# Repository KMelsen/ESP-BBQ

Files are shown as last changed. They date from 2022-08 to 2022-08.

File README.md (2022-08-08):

# ESP-BBQ
This contains all files for an ESP32 based WiFi BBQ thermometer.

* ```ESP-BBQ```: Contains the Arduino sketch with the code
* ```KiCad_PCB```: Contains all KiCad (6.0) files for the PCB
* ```Gerber_Drill_PCB.zip```: ZIP with all files needed to order the PCB
* ```PJ-210B_4-pin_2.5mm_jack.kicad_mod```: Custom KiCad footprint for the PJ-210B 4-pin 2.5mm jack

# Required parts
* **1x** PCB
* **1x** 38-pin ESP32
* **6x** PJ-210B 4-pin 2.5mm jack
* **6x** 100 Nf (104) capacitor
* **6x** 100K Ohm resistor
* **6x** 100K NTC thermistor probe
* **1x** 1.3 inch 128x64 I2C OLED display
* **2x** 19-pin 2.54mm female connector
* **1x** 4-pin 2.54mm female connector
* **8x** M3 20mm bolt
* **16x** M3 nut




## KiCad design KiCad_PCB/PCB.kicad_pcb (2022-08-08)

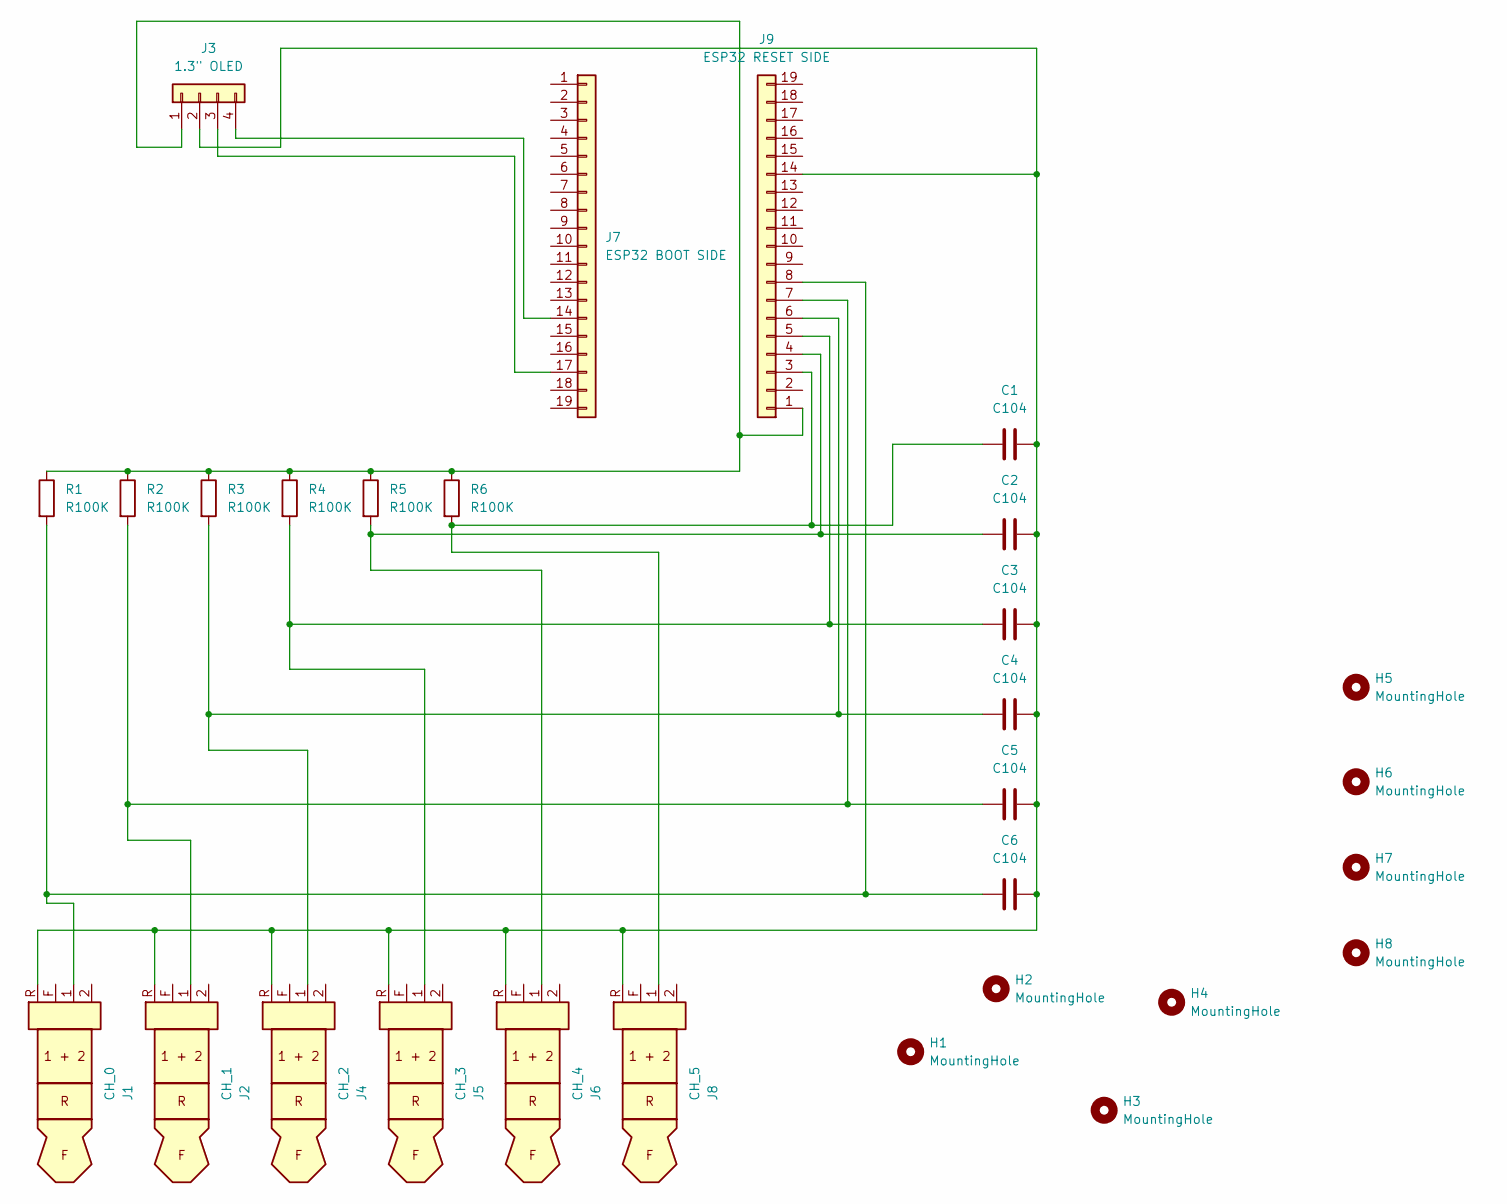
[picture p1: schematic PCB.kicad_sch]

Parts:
C1, C2, C3, C4, C5, C6: C104; C_Disc_D5.0mm_W2.5mm_P2.50mm
H1, H2, H3, H4, H5, H6, H7, H8: MountingHole; MountingHole_3.2mm_M3
J1: CH_0
J2: CH_1
J3: 1.3" OLED; PinSocket_1x04_P2.54mm_Vertical
J4: CH_2
J5: CH_3
J6: CH_4
J7: ESP32 BOOT SIDE; PinSocket_1x19_P2.54mm_Vertical
J8: CH_5
J9: ESP32 RESET SIDE; PinSocket_1x19_P2.54mm_Vertical
R1, R2, R3, R4, R5, R6: R100K; R_Axial_DIN0207_L6.3mm_D2.5mm_P7.62mm_Horizontal

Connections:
unnamed: C1.1, J8.1, J9.3, R6.2
unnamed: C1.2, C2.2, C3.2, C4.2, C5.2, C6.2, J1.R, J2.R, J3.2, J4.R, J5.R, J6.R, J8.R, J9.14
unnamed: C2.1, J6.1, J9.4, R5.2
unnamed: C3.1, J5.1, J9.5, R4.2
unnamed: C4.1, J4.1, J9.6, R3.2
unnamed: C5.1, J2.1, J9.7, R2.2
unnamed: C6.1, J1.1, J9.8, R1.2
unnamed: J3.1, J9.1, R1.1, R2.1, R3.1, R4.1, R5.1, R6.1
unnamed: J3.3, J7.17
unnamed: J3.4, J7.14

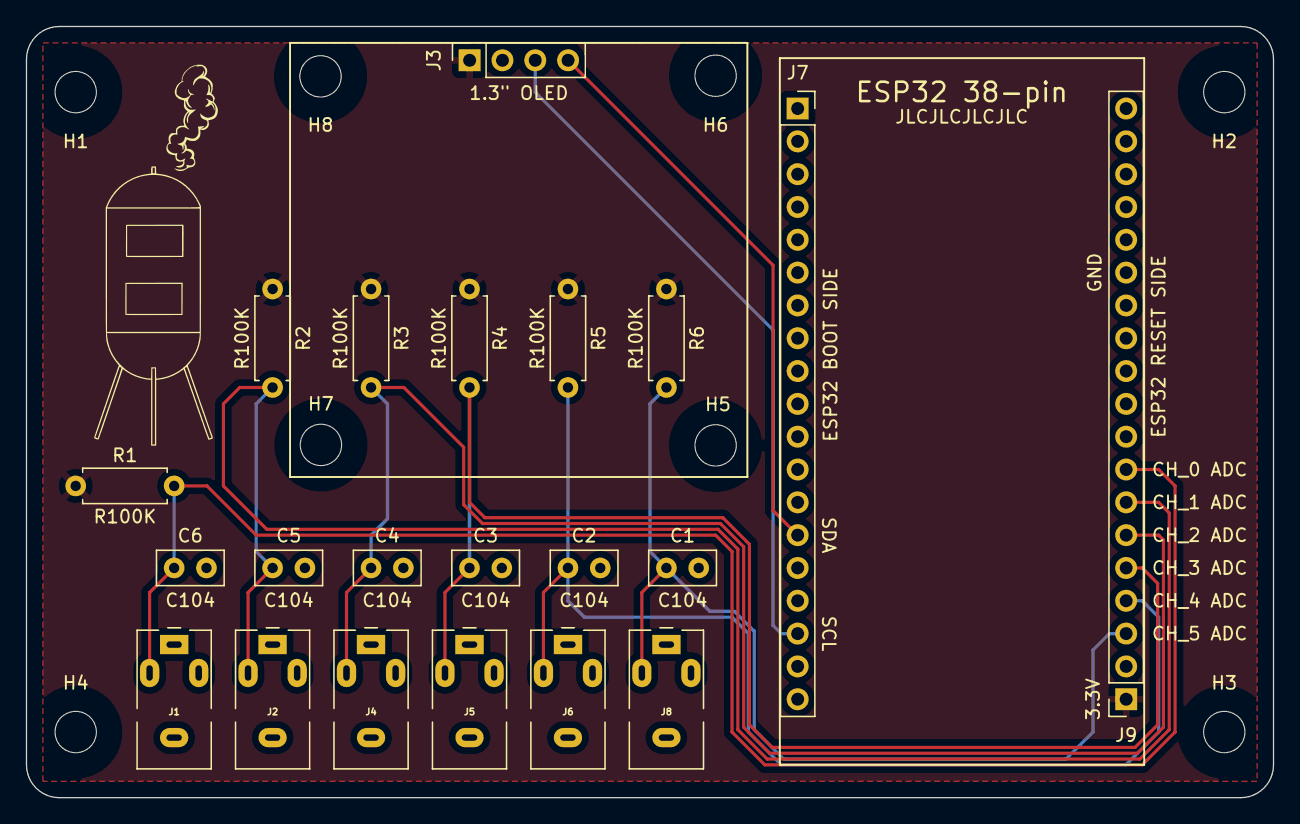
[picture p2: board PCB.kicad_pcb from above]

Board: 2 copper layers, 96.5 x 59.7 mm, 29 parts (0 on the bottom side), 10 nets.

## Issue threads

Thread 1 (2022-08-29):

Possible to calculate in Celsius website?

Relex28, 2022-08-29:
Hi and thank you for this amazing sharing!

is it possible to also convert the temperature to celcius in the website as done on the screen?

kind regards.

KMelsen, 2022-08-29:
```
String calTempF(int channel_pin) {
  float R = calculateResistance(channel_pin);
  float temp_K = 1.0 / (STEINHART_A + (STEINHART_B * log(R)) + (STEINHART_C * pow(log(R), 3.0)));
  float temp_C = round(temp_K - 273.15);
  int cal_temp_C = round(4.95152 + 0.7959 * temp_C);
  if (cal_temp_C < -100) {
    String cal_temp_F = "No probe connected";
    return String(cal_temp_F);
  } else {
    String cal_temp_F = String(round(cal_temp_C * 9 / 5 + 32));
    return String(cal_temp_F);
  }
}
```

You can change the line `String cal_temp_F = String(round(cal_temp_C * 9 / 5 + 32));` to return the temperature in Celsius instead of Fahrenheit.

Then just change the sign from `&deg;F` to `&deg;C` in for all channels
```
    <tr>
    <td><strong>Channel 0&nbsp;&nbsp;&nbsp;&nbsp;&nbsp;&nbsp;&nbsp;&nbsp;&nbsp;&nbsp;&nbsp;&nbsp;</strong>
    </td>
    <td id="ch0tempf" style="text-align:right;">%CH0TEMPF%</td>
    <td>&nbsp;&nbsp;&deg;F</td>
    </tr>
```

Relex28, 2022-08-29:
Many thanks, changed the lines and it works perfect.

Closed 2022-08-29.

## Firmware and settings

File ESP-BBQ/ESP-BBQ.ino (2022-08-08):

// Include libraries
#include <WiFi.h>
#include <ESPAsyncWebServer.h>
#include <SPI.h>
#include <Wire.h>
#include <Adafruit_GFX.h>
#include <Adafruit_SH110X.h>

// OLED information
#define I2C_ADDRESS 0x3C
#define SCREEN_WIDTH 128
#define SCREEN_HEIGHT 64
#define OLED_RESET -1
Adafruit_SH1106G display = Adafruit_SH1106G(SCREEN_WIDTH, SCREEN_HEIGHT, &Wire, OLED_RESET);

// Number of ADC samples for temperature calculation
const int samples = 50;

// Define input channels
#define CH0_INPUT 33
#define CH1_INPUT 32
#define CH2_INPUT 35
#define CH3_INPUT 34
#define CH4_INPUT 39
#define CH5_INPUT 36

// Define resistor and steinhart values
float RESISTOR = 99700;
float STEINHART_A = 0.5508197510e-3;
float STEINHART_B = 2.381337093e-4;
float STEINHART_C = 0.3546777196e-7;

// String temperature variables
String cal_temp_ch0_F = "";
String cal_temp_ch1_F = "";
String cal_temp_ch2_F = "";
String cal_temp_ch3_F = "";
String cal_temp_ch4_F = "";
String cal_temp_ch5_F = "";

// Splash screen logo bitmap, 128x64px
const unsigned char splash_bitmap [] PROGMEM = {
0x00, 0x00, 0x00, 0x00, 0x00, 0x00, 0x00, 0x00, 0x00, 0x00, 0x00, 0x00, 0x00, 0x00, 0x00, 0x00, 
0x00, 0x00, 0x00, 0x00, 0x00, 0x00, 0x00, 0x00, 0x00, 0x00, 0x00, 0x00, 0x00, 0x00, 0x00, 0x00, 
0x00, 0x00, 0x00, 0x00, 0x00, 0x00, 0x00, 0x00, 0x00, 0x00, 0x00, 0x00, 0x00, 0x20, 0x00, 0x00, 
0x00, 0x00, 0x00, 0x00, 0x00, 0x00, 0x00, 0x00, 0x00, 0x00, 0x00, 0x00, 0x00, 0x20, 0x00, 0x00, 
0x00, 0x00, 0x00, 0x00, 0x00, 0x00, 0x00, 0x00, 0x00, 0x00, 0x00, 0x00, 0x00, 0xf8, 0x00, 0x00, 
0x00, 0x00, 0x00, 0x00, 0x00, 0x00, 0x00, 0x00, 0x00, 0x00, 0x00, 0x00, 0x0f, 0xff, 0x80, 0x00, 
0x00, 0x00, 0x00, 0x00, 0x00, 0x00, 0x00, 0x00, 0x00, 0x00, 0x00, 0x00, 0x1f, 0x07, 0xc0, 0x00, 
0x00, 0x00, 0x00, 0x00, 0x00, 0x00, 0x00, 0x00, 0x00, 0x00, 0x00, 0x00, 0x38, 0x00, 0xe0, 0x00, 
0x00, 0x00, 0x00, 0x00, 0x00, 0x00, 0x00, 0x00, 0x00, 0x00, 0x00, 0x00, 0x70, 0x00, 0x70, 0x00, 
0x00, 0x00, 0x00, 0x00, 0x00, 0x00, 0x00, 0x00, 0x00, 0x00, 0x00, 0x00, 0xe0, 0x00, 0x38, 0x00, 
0x00, 0x00, 0x00, 0x00, 0x00, 0x00, 0x00, 0x00, 0x00, 0x00, 0x00, 0x00, 0xc0, 0x00, 0x18, 0x00, 
0x00, 0x00, 0x00, 0x00, 0x00, 0x00, 0x00, 0x00, 0x00, 0x00, 0x00, 0x00, 0xc0, 0x00, 0x18, 0x00, 
0x00, 0x00, 0x00, 0x00, 0x00, 0x00, 0x00, 0x00, 0x00, 0x00, 0x00, 0x00, 0xff, 0xff, 0xf8, 0x00, 
0x00, 0x00, 0x00, 0x00, 0x00, 0x00, 0x00, 0x00, 0x00, 0x00, 0x00, 0x00, 0xff, 0xff, 0xf8, 0x00, 
0x00, 0x00, 0x00, 0x00, 0x00, 0x00, 0x00, 0x00, 0x00, 0x00, 0x00, 0x00, 0xc0, 0x00, 0x18, 0x00, 
0x00, 0x00, 0x00, 0x00, 0x00, 0x00, 0x00, 0x00, 0x00, 0x00, 0x00, 0x00, 0xc0, 0x00, 0x18, 0x00, 
0x00, 0x00, 0x00, 0x00, 0x00, 0x00, 0x00, 0x00, 0x00, 0x00, 0x00, 0x00, 0xcf, 0xff, 0x98, 0x00, 
0x00, 0x00, 0x00, 0x00, 0x00, 0x00, 0x00, 0x00, 0x00, 0x00, 0x00, 0x00, 0xcf, 0xff, 0x98, 0x00, 
0x00, 0x00, 0x00, 0x00, 0x00, 0x00, 0x00, 0x00, 0x00, 0x00, 0x00, 0x00, 0xcc, 0x01, 0x98, 0x00, 
0x00, 0x00, 0x00, 0x00, 0x00, 0x00, 0x00, 0x00, 0x00, 0x00, 0x00, 0x00, 0xcc, 0x01, 0x98, 0x00, 
0x00, 0x00, 0x00, 0x00, 0x00, 0x00, 0x00, 0x00, 0x00, 0x00, 0x00, 0x00, 0xcc, 0x01, 0x98, 0x00, 
0x00, 0x60, 0x1b, 0x01, 0xfd, 0x81, 0xfc, 0xfe, 0x3f, 0x80, 0x00, 0x00, 0xcc, 0x01, 0x98, 0x00, 
0x00, 0x60, 0x18, 0x01, 0x80, 0x01, 0x86, 0xc3, 0x60, 0xc0, 0x00, 0x00, 0xcf, 0xff, 0x98, 0x00, 
0x00, 0x33, 0x30, 0x01, 0x80, 0x01, 0x86, 0xc3, 0x60, 0xc0, 0x00, 0x00, 0xcf, 0xff, 0x98, 0x00, 
0x00, 0x33, 0x33, 0x01, 0x81, 0x81, 0x86, 0xc3, 0x60, 0xc0, 0x00, 0x00, 0xc0, 0x00, 0x18, 0x00, 
0x00, 0x33, 0x33, 0x01, 0xf9, 0x81, 0xfc, 0xfe, 0x60, 0xc0, 0x00, 0x00, 0xc0, 0x00, 0x18, 0x00, 
0x00, 0x1f, 0xe3, 0x3d, 0x81, 0x81, 0x86, 0xc3, 0x60, 0xc0, 0x00, 0x00, 0xc0, 0x00, 0x18, 0x00, 
0x00, 0x1f, 0xe3, 0x01, 0x81, 0x81, 0x86, 0xc3, 0x63, 0xc0, 0x00, 0x00, 0xc0, 0x00, 0x18, 0x00, 
0x00, 0x0c, 0xc3, 0x01, 0x81, 0x81, 0x86, 0xc3, 0x61, 0xc0, 0x00, 0x00, 0xc0, 0x00, 0x18, 0x00, 
0x00, 0x0c, 0xc3, 0x01, 0x81, 0x81, 0xfc, 0xfe, 0x3f, 0x80, 0x00, 0x00, 0xcf, 0xff, 0x98, 0x00, 
0x00, 0x00, 0x00, 0x00, 0x00, 0x00, 0x00, 0x00, 0x00, 0xc0, 0x00, 0x00, 0xcf, 0xff, 0x98, 0x00, 
0x00, 0x00, 0x00, 0x00, 0x00, 0x00, 0x00, 0x00, 0x00, 0x00, 0x00, 0x00, 0xcc, 0x01, 0x98, 0x00, 
0x00, 0x00, 0x00, 0x00, 0x00, 0x00, 0x00, 0x00, 0x00, 0x00, 0x00, 0x00, 0xcc, 0x01, 0x98, 0x00, 
0x00, 0x00, 0x00, 0x00, 0x00, 0x00, 0x00, 0x00, 0x00, 0x00, 0x00, 0x00, 0xcc, 0x01, 0x98, 0x00, 
0x00, 0x7f, 0xb0, 0x00, 0x00, 0x00, 0x00, 0x00, 0x00, 0x00, 0x00, 0x00, 0xcc, 0x01, 0x98, 0x00, 
0x00, 0x0c, 0x30, 0x00, 0x00, 0x00, 0x00, 0x00, 0x00, 0x30, 0x00, 0x00, 0xcf, 0xff, 0x98, 0x00, 
0x00, 0x0c, 0x30, 0x00, 0x00, 0x00, 0x00, 0x00, 0x00, 0x30, 0x00, 0x00, 0xcf, 0xff, 0x98, 0x00, 
0x00, 0x0c, 0x3f, 0x1e, 0x7b, 0xfe, 0x3c, 0xff, 0x8f, 0x39, 0xe7, 0x80, 0xc0, 0x00, 0x18, 0x00, 
0x00, 0x0c, 0x39, 0xb3, 0x63, 0x33, 0x66, 0xcc, 0xd9, 0xb3, 0x36, 0x00, 0xc0, 0x00, 0x18, 0x00, 
0x00, 0x0c, 0x31, 0xbf, 0x63, 0x33, 0x66, 0xcc, 0xdf, 0xb3, 0xf6, 0x00, 0xff, 0xff, 0xf8, 0x00, 
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
};

// WiFi information.
const char* ssid = "Replace with SSID";
const char* password = "Replace with password";
AsyncWebServer server(80);

// Functions
double analogReadAverage(int channel_pin) {
  int i;
  int maxValue = 0;
  int minValue = 5000;
  double sumValue = 0;
  double result;
  int reading;
  for (i = 0; i < 8; i++) {
    reading = analogRead(channel_pin);
    sumValue += (double)reading;
    if (reading > maxValue) maxValue = reading;
    if (reading < minValue) minValue = reading;
  }
  result = (sumValue - (double)maxValue - (double)minValue) / 6;
  return result;
}

double calculateResistance(int channel_pin) {
  double resistanceNTC = 0;
  int x;
  for (x = 0; x < samples; x++) {
    resistanceNTC += analogReadAverage(channel_pin);
  }
  resistanceNTC /= samples;
  resistanceNTC = (float)(RESISTOR * resistanceNTC) / (4095 - resistanceNTC);
  return resistanceNTC;
}

String calTempF(int channel_pin) {
  float R = calculateResistance(channel_pin);
  float temp_K = 1.0 / (STEINHART_A + (STEINHART_B * log(R)) + (STEINHART_C * pow(log(R), 3.0)));
  float temp_C = round(temp_K - 273.15);
  int cal_temp_C = round(4.95152 + 0.7959 * temp_C);
  if (cal_temp_C < -100) {
    String cal_temp_F = "No probe connected";
    return String(cal_temp_F);
  } else {
    String cal_temp_F = String(round(cal_temp_C * 9 / 5 + 32));
    return String(cal_temp_F);
  }
}

// html code
const char index_html[] PROGMEM = R"rawliteral(
<!DOCTYPE HTML><html>
<head>
  <meta name="viewport" content="width=device-width, initial-scale=1">
  <link rel="stylesheet" href="https://use.fontawesome.com/releases/v5.7.2/css/all.css" integrity="sha384-fnmOCqbTlWIlj8LyTjo7mOUStjsKC4pOpQbqyi7RrhN7udi9RwhKkMHpvLbHG9Sr" crossorigin="anonymous">
  <style>
    html {
     font-family: Arial;
     display: inline-block;
     margin: 15px auto;
     text-align: center;
    }
  </style>
</head>
<body>
  <h1>Smoker Temperature</h1>
  <table style="width: 80.1867; border-collapse: collapse; margin-left: auto; margin-right: auto;" border="0">
  <tbody>
    <tr>
    <td><strong>Channel 0&nbsp;&nbsp;&nbsp;&nbsp;&nbsp;&nbsp;&nbsp;&nbsp;&nbsp;&nbsp;&nbsp;&nbsp;</strong></td>
    <td id="ch0tempf" style="text-align:right;">%CH0TEMPF%</td>
    <td>&nbsp;&nbsp;&deg;F</td>
    </tr>
    <tr>
    <td><strong>Channel 1&nbsp;&nbsp;&nbsp;&nbsp;&nbsp;&nbsp;&nbsp;&nbsp;&nbsp;&nbsp;&nbsp;&nbsp;</strong></td>
    <td id="ch1tempf" style="text-align:right;">%CH1TEMPF%</td>
    <td>&nbsp;&nbsp;&deg;F</td>
    </tr>
    <tr>
    <td><strong>Channel 2&nbsp;&nbsp;&nbsp;&nbsp;&nbsp;&nbsp;&nbsp;&nbsp;&nbsp;&nbsp;&nbsp;&nbsp;</strong></td>
    <td id="ch2tempf" style="text-align:right;">%CH2TEMPF%</td>
    <td>&nbsp;&nbsp;&deg;F</td>
    </tr>
    <tr>
    <td><strong>Channel 3&nbsp;&nbsp;&nbsp;&nbsp;&nbsp;&nbsp;&nbsp;&nbsp;&nbsp;&nbsp;&nbsp;&nbsp;</strong></td>
    <td id="ch3tempf" style="text-align:right;">%CH3TEMPF%</td>
    <td>&nbsp;&nbsp;&deg;F</td>
    </tr>
    <tr>
    <td><strong>Channel 4&nbsp;&nbsp;&nbsp;&nbsp;&nbsp;&nbsp;&nbsp;&nbsp;&nbsp;&nbsp;&nbsp;&nbsp;</strong></td>
    <td id="ch4tempf" style="text-align:right;">%CH4TEMPF%</td>
    <td>&nbsp;&nbsp;&deg;F</td>
    </tr>
    <tr>
    <td><strong>Channel 5&nbsp;&nbsp;&nbsp;&nbsp;&nbsp;&nbsp;&nbsp;&nbsp;&nbsp;&nbsp;&nbsp;&nbsp;</strong></td>
    <td id="ch5tempf" style="text-align:right;">%CH5TEMPF%</td>
    <td>&nbsp;&nbsp;&deg;F</td>
    </tr>
  </tbody>
  </table>
</body>
<script>
setInterval(function ( ) {
  var xhttp = new XMLHttpRequest();
  xhttp.onreadystatechange = function() {
    if (this.readyState == 4 && this.status == 200) {
      document.getElementById("ch0tempf").innerHTML = this.responseText;
    }
  };
  xhttp.open("GET", "/ch0tempf", true);
  xhttp.send();
}, 1000) ;
setInterval(function ( ) {
  var xhttp = new XMLHttpRequest();
  xhttp.onreadystatechange = function() {
    if (this.readyState == 4 && this.status == 200) {
      document.getElementById("ch1tempf").innerHTML = this.responseText;
    }
  };
  xhttp.open("GET", "/ch1tempf", true);
  xhttp.send();
}, 1000) ;
setInterval(function ( ) {
  var xhttp = new XMLHttpRequest();
  xhttp.onreadystatechange = function() {
    if (this.readyState == 4 && this.status == 200) {
      document.getElementById("ch2tempf").innerHTML = this.responseText;
    }
  };
  xhttp.open("GET", "/ch2tempf", true);
  xhttp.send();
}, 1000) ;
setInterval(function ( ) {
  var xhttp = new XMLHttpRequest();
  xhttp.onreadystatechange = function() {
    if (this.readyState == 4 && this.status == 200) {
      document.getElementById("ch3tempf").innerHTML = this.responseText;
    }
  };
  xhttp.open("GET", "/ch3tempf", true);
  xhttp.send();
}, 1000) ;
setInterval(function ( ) {
  var xhttp = new XMLHttpRequest();
  xhttp.onreadystatechange = function() {
    if (this.readyState == 4 && this.status == 200) {
      document.getElementById("ch4tempf").innerHTML = this.responseText;
    }
  };
  xhttp.open("GET", "/ch4tempf", true);
  xhttp.send();
}, 1000) ;
setInterval(function ( ) {
  var xhttp = new XMLHttpRequest();
  xhttp.onreadystatechange = function() {
    if (this.readyState == 4 && this.status == 200) {
      document.getElementById("ch5tempf").innerHTML = this.responseText;
    }
  };
  xhttp.open("GET", "/ch5tempf", true);
  xhttp.send();
}, 1000) ;
</script>
</html>)rawliteral";

// Replace html placeholders
String processor(const String& var){
  //Serial.println(var);
  if (var == "CH0TEMPF"){
    return cal_temp_ch0_F;
  }
  else if (var == "CH1TEMPF"){
    return cal_temp_ch1_F;
  }
  else if (var == "CH2TEMPF") {
    return cal_temp_ch2_F;
  }
  else if (var == "CH3TEMPF") {
    return cal_temp_ch3_F;
  }
  else if (var == "CH4TEMPF") {
    return cal_temp_ch4_F;
  }
  else if (var == "CH5TEMPF") {
    return cal_temp_ch5_F;
  }
  return String();
}

void setup() {
  Serial.begin(115200);
  delay(1000);
  analogSetAttenuation(ADC_11db);
  display.begin(I2C_ADDRESS, true);
  delay(1000);
  display.clearDisplay();
  display.drawBitmap(0, 0, splash_bitmap, 128, 64, SH110X_WHITE);
  display.display();
  delay(3000);
  display.clearDisplay();
  display.setTextSize(1);
  display.setTextColor(SH110X_WHITE);
  display.setCursor(0, 0);
  WiFi.begin(ssid, password);
  Serial.println("Connecting to WiFi");
  display.println("Connecting to WiFi");
  display.display();
  while (WiFi.status() != WL_CONNECTED) {
    delay(500);
    Serial.print(".");
    display.print(".");
    display.display();
  }
  Serial.println();
  display.clearDisplay();
  display.setCursor(0, 0);
  Serial.println(WiFi.localIP());
  display.println("Available at");
  display.println();
  display.println(WiFi.localIP());
  display.display();
  delay(3000);

  // Route for root / web page
  server.on("/", HTTP_GET, [](AsyncWebServerRequest *request){
    request->send_P(200, "text/html", index_html, processor);
  });
  server.on("/ch0tempf", HTTP_GET, [](AsyncWebServerRequest *request){
    request->send_P(200, "text/plain", calTempF(CH0_INPUT).c_str());
  });
  server.on("/ch1tempf", HTTP_GET, [](AsyncWebServerRequest *request){
    request->send_P(200, "text/plain", calTempF(CH1_INPUT).c_str());
  });
  server.on("/ch2tempf", HTTP_GET, [](AsyncWebServerRequest *request){
    request->send_P(200, "text/plain", calTempF(CH2_INPUT).c_str());
  });
  server.on("/ch3tempf", HTTP_GET, [](AsyncWebServerRequest *request){
    request->send_P(200, "text/plain", calTempF(CH3_INPUT).c_str());
  });
  server.on("/ch4tempf", HTTP_GET, [](AsyncWebServerRequest *request){
    request->send_P(200, "text/plain", calTempF(CH4_INPUT).c_str());
  });
  server.on("/ch5tempf", HTTP_GET, [](AsyncWebServerRequest *request){
    request->send_P(200, "text/plain", calTempF(CH5_INPUT).c_str());
  });
  
  // Start server
  server.begin();
}

void loop() {
  // Clear display and set cursor for printing data
  display.clearDisplay();
  display.setCursor(0, 1);

  // Calculate thermistor resistances.
  float r_ch_0 = calculateResistance(CH0_INPUT);
  float r_ch_1 = calculateResistance(CH1_INPUT);
  float r_ch_2 = calculateResistance(CH2_INPUT);
  float r_ch_3 = calculateResistance(CH3_INPUT);
  float r_ch_4 = calculateResistance(CH4_INPUT);
  float r_ch_5 = calculateResistance(CH5_INPUT);
  
  // Calculate temperatures in K using Steinhart-Hart
  float temp_k_ch_0 = 1.0 / (STEINHART_A + (STEINHART_B * log(r_ch_0)) + (STEINHART_C * pow(log(r_ch_0), 3.0)));
  float temp_k_ch_1 = 1.0 / (STEINHART_A + (STEINHART_B * log(r_ch_1)) + (STEINHART_C * pow(log(r_ch_1), 3.0)));
  float temp_k_ch_2 = 1.0 / (STEINHART_A + (STEINHART_B * log(r_ch_2)) + (STEINHART_C * pow(log(r_ch_2), 3.0)));
  float temp_k_ch_3 = 1.0 / (STEINHART_A + (STEINHART_B * log(r_ch_3)) + (STEINHART_C * pow(log(r_ch_3), 3.0)));
  float temp_k_ch_4 = 1.0 / (STEINHART_A + (STEINHART_B * log(r_ch_4)) + (STEINHART_C * pow(log(r_ch_4), 3.0)));
  float temp_k_ch_5 = 1.0 / (STEINHART_A + (STEINHART_B * log(r_ch_5)) + (STEINHART_C * pow(log(r_ch_5), 3.0)));

  // Convert to C and correct using calibration curve
  float temp_ch_0 = round(temp_k_ch_0 - 273.15);
  float temp_ch_1 = round(temp_k_ch_1 - 273.15);
  float temp_ch_2 = round(temp_k_ch_2 - 273.15);
  float temp_ch_3 = round(temp_k_ch_3 - 273.15);
  float temp_ch_4 = round(temp_k_ch_4 - 273.15);
  float temp_ch_5 = round(temp_k_ch_5 - 273.15);
  int cal_temp_ch_0 = round(4.95152 + 0.7959 * temp_ch_0); 
  int cal_temp_ch_1 = round(4.95152 + 0.7959 * temp_ch_1); 
  int cal_temp_ch_2 = round(4.95152 + 0.7959 * temp_ch_2);
  int cal_temp_ch_3 = round(4.95152 + 0.7959 * temp_ch_3);  
  int cal_temp_ch_4 = round(4.95152 + 0.7959 * temp_ch_4); 
  int cal_temp_ch_5 = round(4.95152 + 0.7959 * temp_ch_5);
  int cal_temp_ch_0_F_OLED = round(cal_temp_ch_0 * 9 / 5 + 32);
  int cal_temp_ch_1_F_OLED = round(cal_temp_ch_1 * 9 / 5 + 32);
  int cal_temp_ch_2_F_OLED = round(cal_temp_ch_2 * 9 / 5 + 32);
  int cal_temp_ch_3_F_OLED = round(cal_temp_ch_3 * 9 / 5 + 32);
  int cal_temp_ch_4_F_OLED = round(cal_temp_ch_4 * 9 / 5 + 32);
  int cal_temp_ch_5_F_OLED = round(cal_temp_ch_5 * 9 / 5 + 32);

  String cal_temp_ch_0_F = calTempF(CH0_INPUT);
  String cal_temp_ch_1_F = calTempF(CH1_INPUT);
  String cal_temp_ch_2_F = calTempF(CH2_INPUT);
  String cal_temp_ch_3_F = calTempF(CH3_INPUT);
  String cal_temp_ch_4_F = calTempF(CH4_INPUT);
  String cal_temp_ch_5_F = calTempF(CH5_INPUT);
  
  // Print temperature on OLED display
  if (cal_temp_ch_0 < -200) {
    display.println("Ch 0: No probe");
  } else {
    display.println((String) "Ch 0: " + cal_temp_ch_0 + " C  " + cal_temp_ch_0_F_OLED + " F");
  }
  display.setCursor(0, 12);
  if (cal_temp_ch_1 < -200) {
    display.println("Ch 1: No probe");
  } else {
    display.println((String) "Ch 1: " + cal_temp_ch_1 + " C  " + cal_temp_ch_1_F_OLED + " F");
  }
  display.setCursor(0, 23);
  if (cal_temp_ch_2 < -200) {
    display.println("Ch 2: No probe");
  } else {
    display.println((String) "Ch 2: " + cal_temp_ch_2 + " C  " + cal_temp_ch_2_F_OLED + " F");
  }
  display.setCursor(0, 34);
  if (cal_temp_ch_3 < -200) {
    display.println("Ch 3: No probe");
  } else {
    display.println((String) "Ch 3: " + cal_temp_ch_3 + " C  " + cal_temp_ch_3_F_OLED + " F");
  }
  display.setCursor(0, 45);
  if (cal_temp_ch_4 < -200) {
    display.println("Ch 4: No probe");
  } else {
    display.println((String) "Ch 4: " + cal_temp_ch_4 + " C  " + cal_temp_ch_4_F_OLED + " F");
  }
  display.setCursor(0, 56);
  if (cal_temp_ch_5 < -200) {
    display.println("Ch 5: No probe");
  } else {
    display.println((String) "Ch 5: " + cal_temp_ch_5 + " C  " + cal_temp_ch_5_F_OLED + " F");
  }
  display.display();
  
  delay(1000);
}
